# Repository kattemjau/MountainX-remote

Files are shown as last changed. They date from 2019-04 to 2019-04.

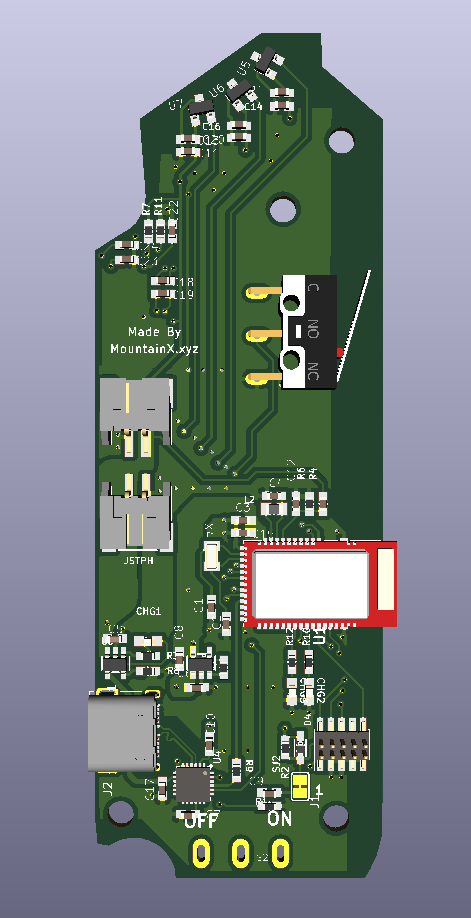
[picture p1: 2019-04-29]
Images/Front.PNG

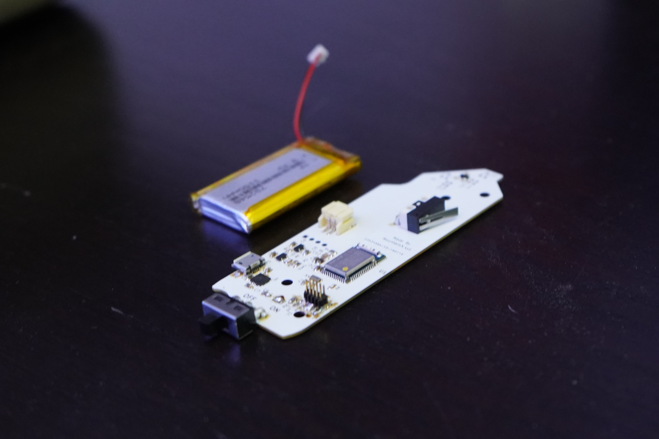
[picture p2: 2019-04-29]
Images/DSC02161.JPG

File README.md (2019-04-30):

# MountainX-remote
PCB of remote, designed in Kicad
Inspired by Adafruit, and SolidGeek

https://learn.adafruit.com/bluefruit-nrf52-feather-learning-guide?view=all#downloads

https://www.electric-skateboard.builders/t/simple-3d-printed-nrf-remote-arduino-controlled/28543

V3 is not yet tested

Arduino compadible CODE can be found here:
https://github.com/Heplaphon/MountainX-Remote

Follow setupguide from Adafruit: https://learn.adafruit.com/bluefruit-nrf52-feather-learning-guide?view=all#arduino-bsp-setup

V2 up and working with Arduino IDE, can be programmed over USB, JTAG and OTA (bluetooth)

3D model of PCB can be found here:
https://github.com/kattemjau/MountainX-remote/tree/master/3D%20model

3D model of remote can be found here:
https://github.com/kattemjau/MountainX-remote/tree/master/3D%20model/V2

Images can be found here:
https://github.com/kattemjau/MountainX-remote/tree/master/Images

Features:

3 Hall sensors for more accurate readings, 
Nordic NRF52 Bluetooth 5, Arm Cotex m4,
Oled screen with telematry from Vesc: Speed, distance, battery voltage, error codes e.t.c, 
Remote battery reading, 
1A Fast charger, 
Long battery life, 
Dual battery to prevent battery disconnect due to shaking, 
Spring loaded knob and trigger, 
Deadmans switch, 
Opensource reprogrammable firmware with arduino IDE, 
Connects with up to 20 clients, long range and high bandwidth,

Changes:

3D model now available, 
Integrated OLED screen, 
Correct angles on Hall sensors, 
Extra battery plug, 
More leds, 
More decoupling caps, 
Better layout, 
Changes to footprints, 
NOW USB C, 

Note:
Jtag programming header is mirrored, just flip the cable to get it to work. "Jtag is not needed"
https://shop-us.segger.com/J_Link_EDU_mini_p/8.08.91.htm

Footprint for Raytac NRF52832 not correct, and SS12D11 (SWITCH) is missing

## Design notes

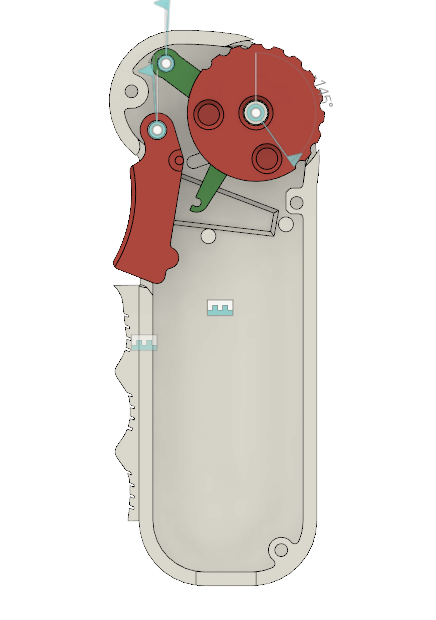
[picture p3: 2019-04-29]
Images/Mechanics.PNG

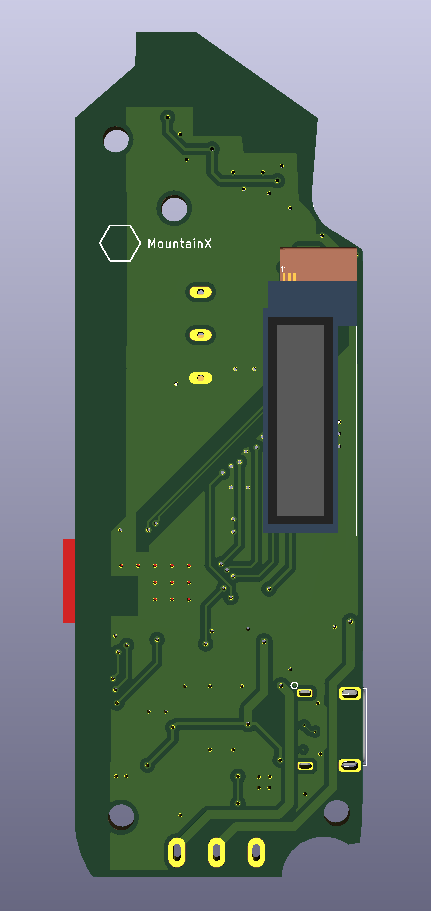
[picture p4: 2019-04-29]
Images/Back.PNG

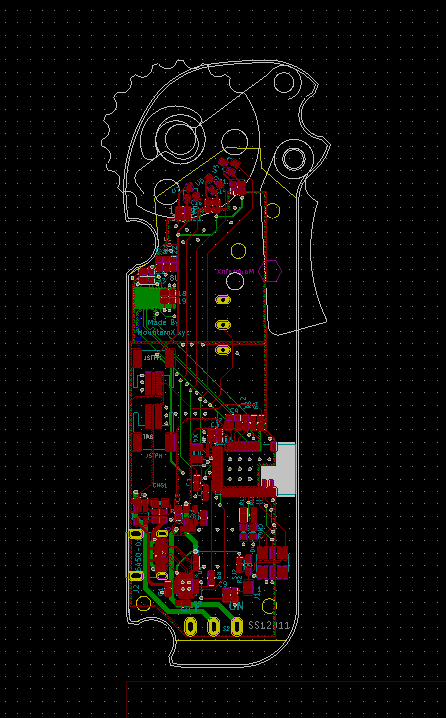
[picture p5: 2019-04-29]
Images/BRD.PNG

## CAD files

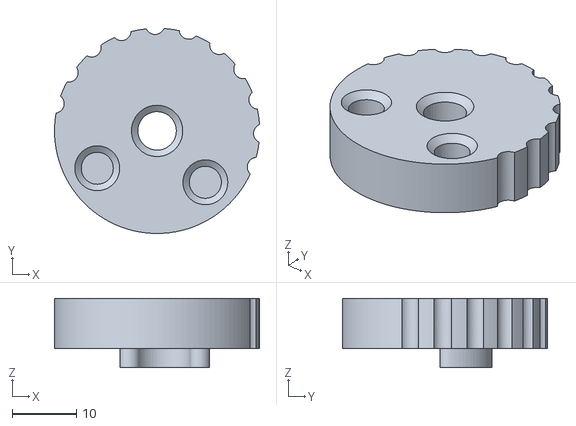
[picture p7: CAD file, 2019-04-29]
3D model/V2/wheel.stl
32.0 x 32.0 x 10.8

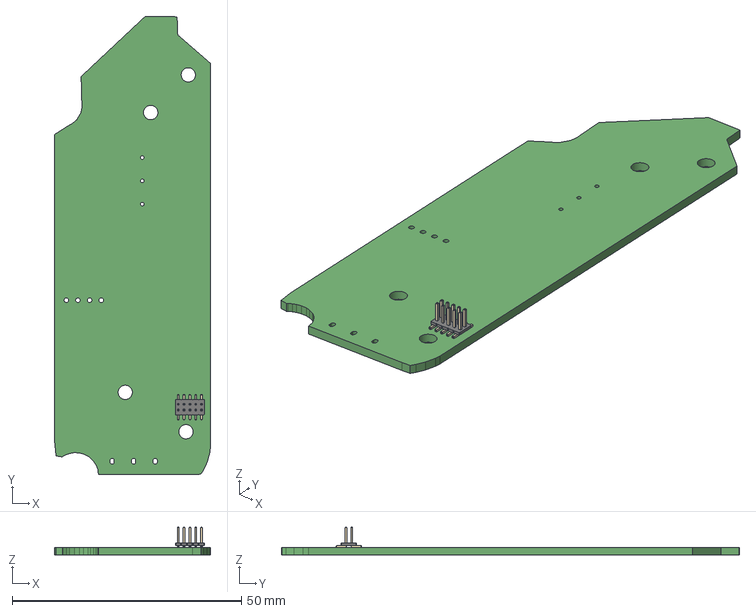
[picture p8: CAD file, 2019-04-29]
eBoard_remote_control.step
34.0 x 99.9 x 6.05 mm

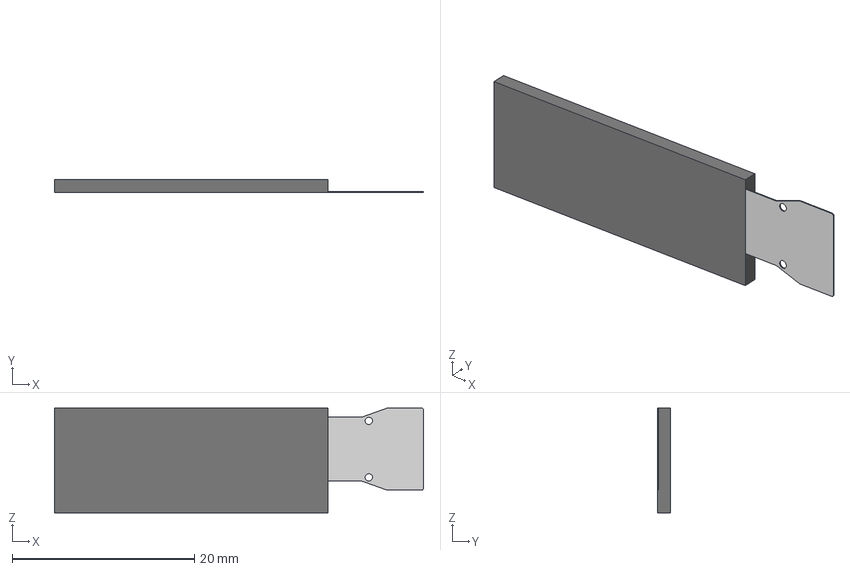
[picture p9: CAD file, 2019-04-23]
KiCad-SSD1306_OLED-0.91-128x32-master/KiCad-SSD1306_OLED-0.91-128x32-master/SSD1306_OLED-0.91-128x32.step
40.5 x 1.45 x 11.5 mm

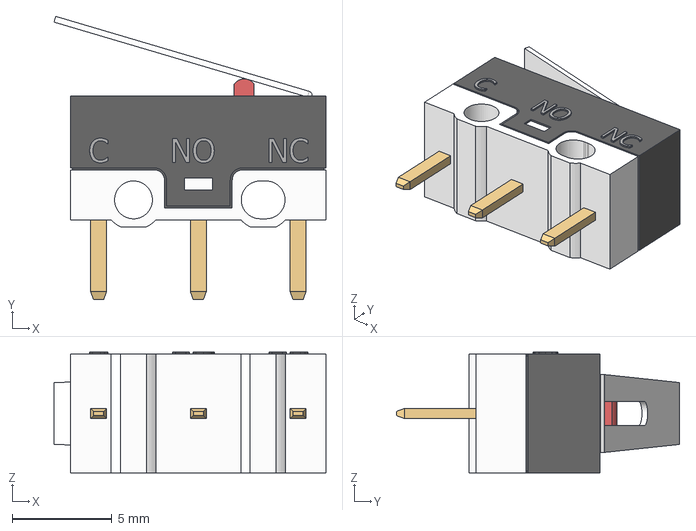
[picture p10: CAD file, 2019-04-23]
KiCad-SSD1306_OLED-0.91-128x32-master/SIngle part PCB micro switch.stp
13.6 x 14.2 x 6.05 mm

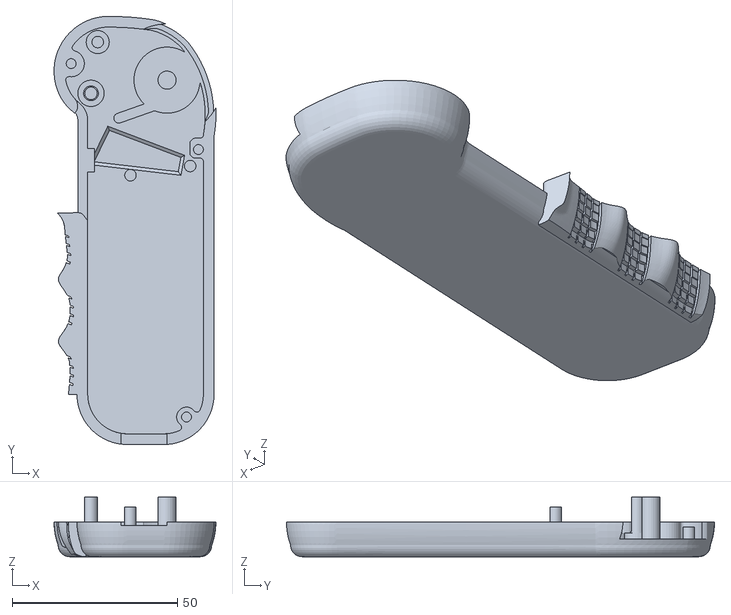
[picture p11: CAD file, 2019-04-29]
3D model/V2/Back.stl
49.0 x 129.5 x 18.0

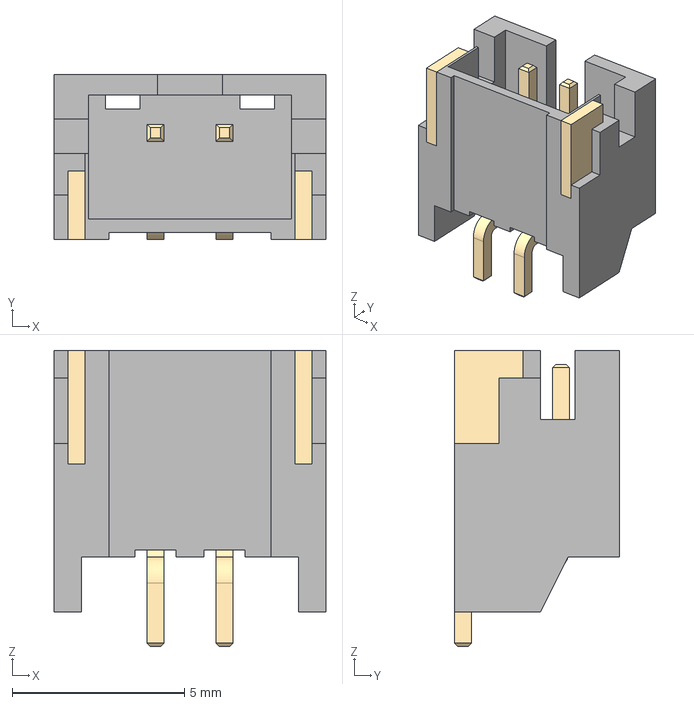
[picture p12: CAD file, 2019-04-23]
KiCad-SSD1306_OLED-0.91-128x32-master/S2B-PH-SM4-TB.step
7.90 x 4.80 x 8.60 mm

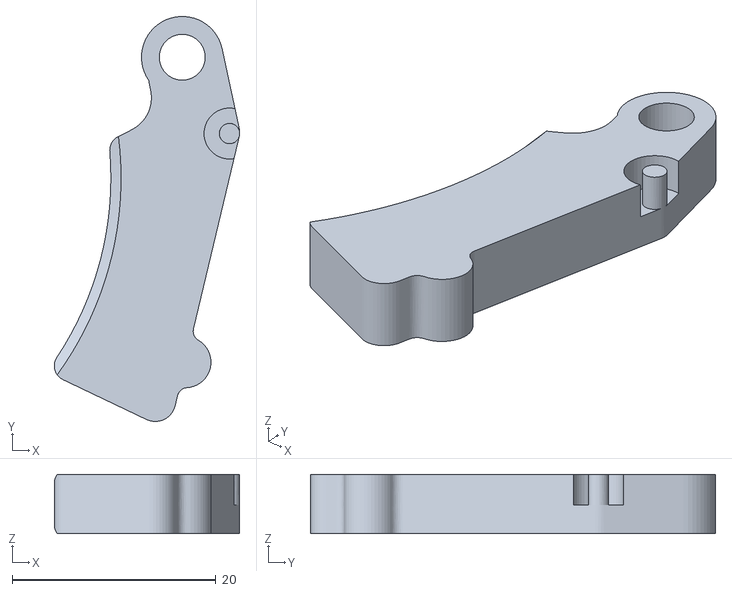
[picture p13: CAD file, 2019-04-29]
3D model/V2/Trigger.stl
18.2 x 39.7 x 5.80

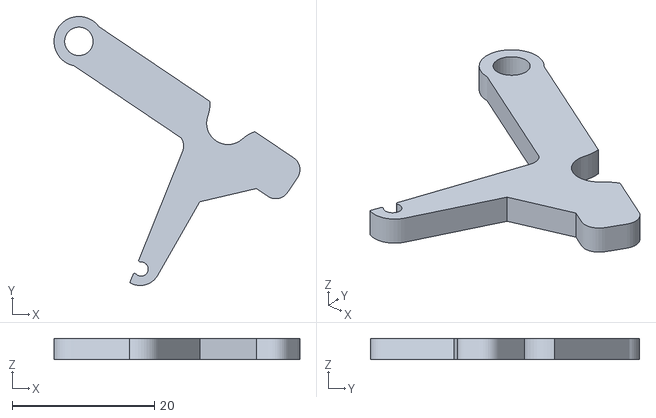
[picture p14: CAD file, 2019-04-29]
3D model/V2/Lever.stl
34.6 x 37.8 x 3.00

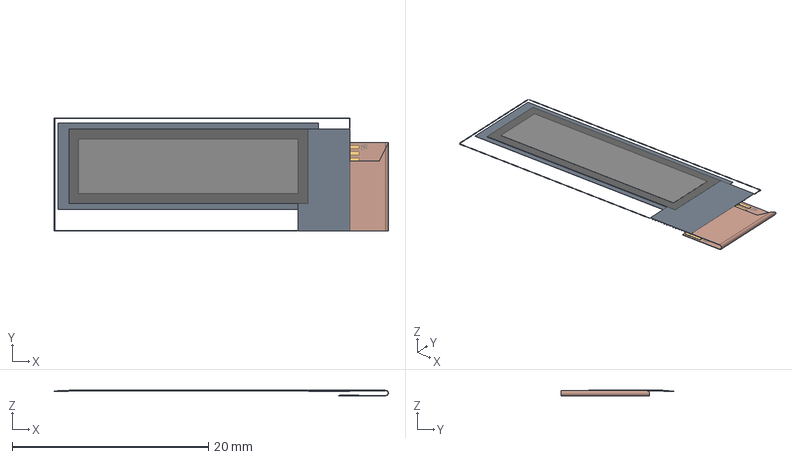
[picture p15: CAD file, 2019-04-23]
KiCad-SSD1306_OLED-0.91-128x32-master/0.91in OLED - Folded Flush - Without Glass.stp
34.1 x 11.5 x 0.621 mm

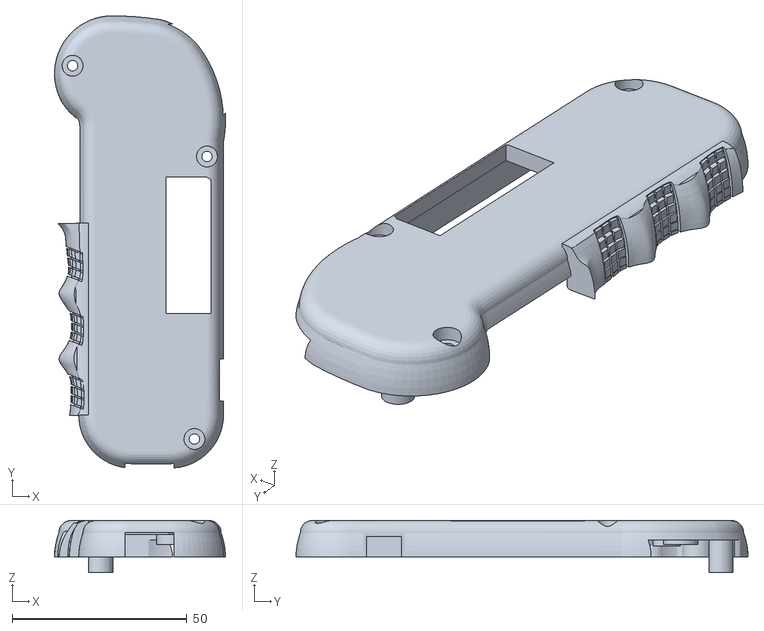
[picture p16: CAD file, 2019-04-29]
3D model/V2/Front.stl
49.0 x 129.5 x 14.9

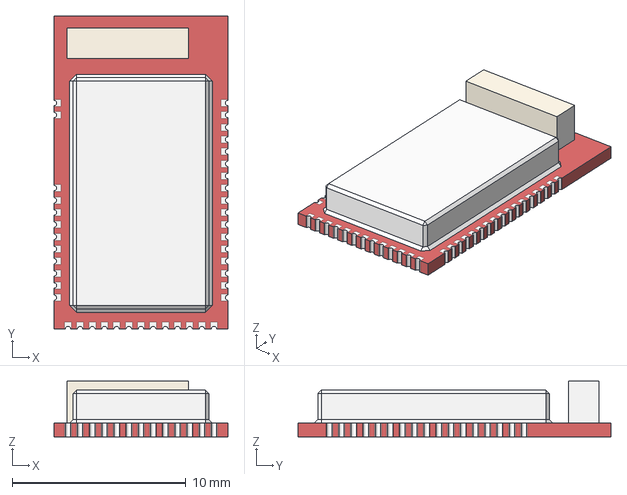
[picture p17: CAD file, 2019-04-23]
KiCad-SSD1306_OLED-0.91-128x32-master/Raytac-MDBT40.step
10.0 x 18.0 x 3.20 mm

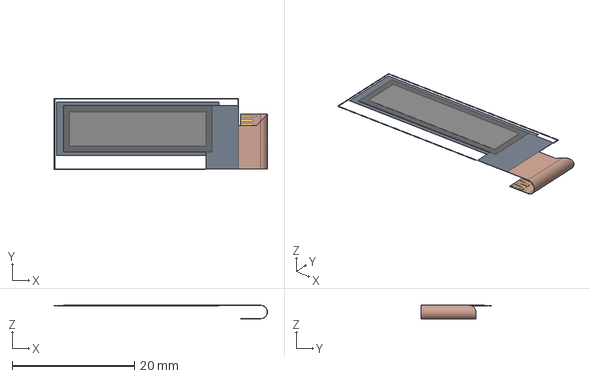
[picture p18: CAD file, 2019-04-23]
KiCad-SSD1306_OLED-0.91-128x32-master/0.91in OLED - Folded - Without Glass.stp
34.9 x 11.5 x 2.29 mm

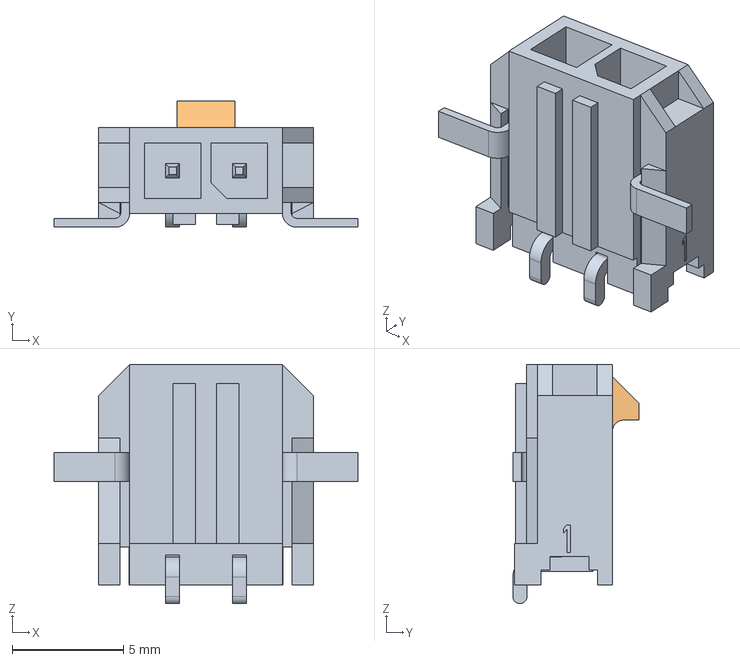
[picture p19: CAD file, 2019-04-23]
KiCad-SSD1306_OLED-0.91-128x32-master/43650-0212_stp/436500212.stp
13.7 x 5.67 x 10.7 mm

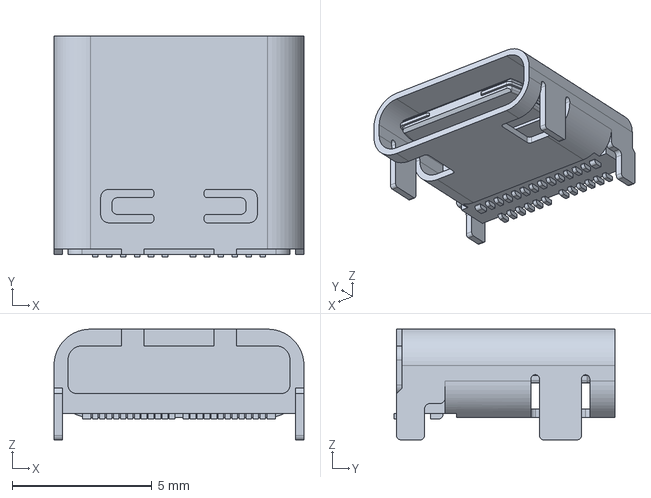
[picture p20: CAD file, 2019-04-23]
KiCad-SSD1306_OLED-0.91-128x32-master/1054500101.stp
8.94 x 7.90 x 3.96 mm

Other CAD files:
KiCad-SSD1306_OLED-0.91-128x32-master/S2B-PH-SM4-TB.SLDPRT

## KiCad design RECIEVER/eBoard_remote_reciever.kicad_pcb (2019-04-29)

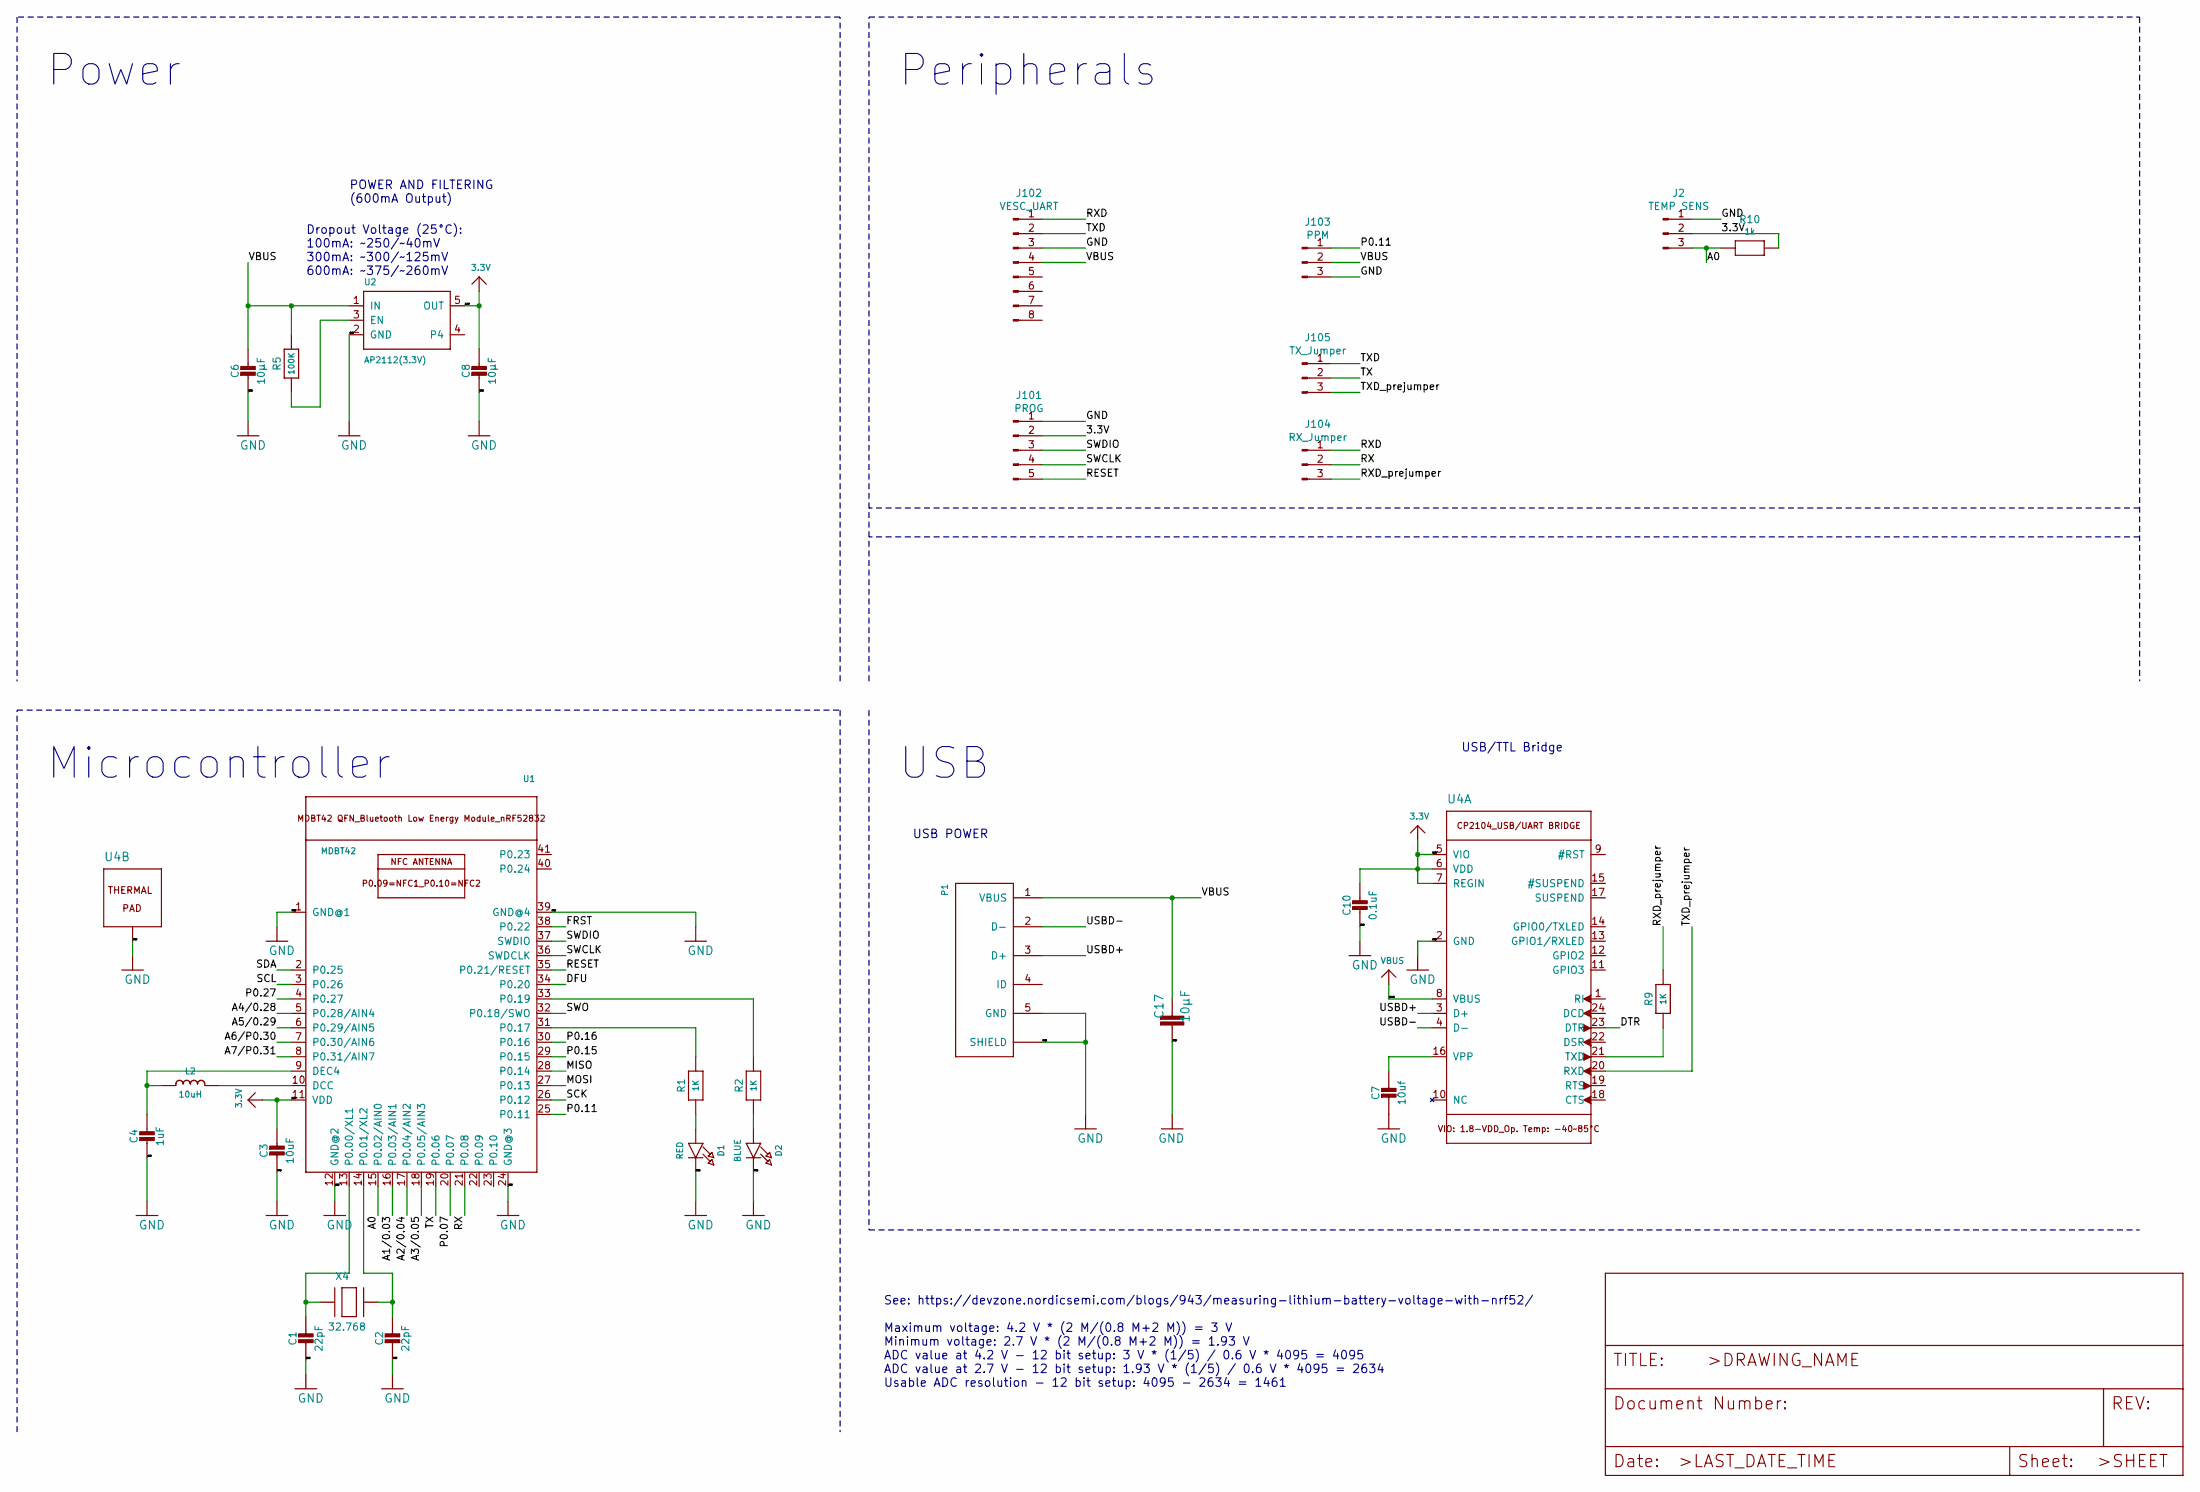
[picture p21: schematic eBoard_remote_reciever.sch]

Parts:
C1, C2: 22pF; 0603-NO
C3: 10uF; 0805-NO
C4: 1uF; 0603-NO
C6, C8: 10µF; 0805-NO
C7: 10uf; 0805-NO
C10: 0.1uF; 0603-NO
C17: 10µF; C0603
D1: RED; D_0805_2012Metric
D2: BLUE; D_0805_2012Metric
J2: TEMP SENS; PinHeader_1x03_P2.54mm_Vertical
J101: PROG; PinHeader_1x05_P2.54mm_Vertical
J102: VESC_UART; PinHeader_1x09_P2.54mm_Vertical
J103: PPM; PinHeader_1x03_P2.54mm_Vertical
J104: RX_Jumper; PinHeader_1x03_P2.54mm_Vertical
J105: TX_Jumper; PinHeader_1x03_P2.54mm_Vertical
L2: 10uH; 0805-NO
P1: USB; USB-MICRO-B
R1, R2, R9: 1K; 0603-NO
R5: 100K; 0603-NO
R10: 1k; R_0603_1608Metric
U1: MDBT42; BLE_MODULE_RAYTAC_MDBT42
U2: AP2112(3.3V); SOT23-5
U4: CP2104; QFN24_4MM_SMSC
X4: 32.768; XTAL3215

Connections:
3.3V: C3.1, C8.1, C10.1, J2.2, J101.2, R10.1, U1.11 (VDD), U2.5 (OUT), U4.5 (VIO), U4.6 (VDD), U4.7 (REGIN)
/A0: J2.3, R10.2, U1.15 (P0.02/AIN0)
/A1/0.03: U1.16 (P0.03/AIN1)
/A2/0.04: U1.17 (P0.04/AIN2)
/A3/0.05: U1.18 (P0.05/AIN3)
/A4/0.28: U1.5 (P0.28/AIN4)
/A5/0.29: U1.6 (P0.29/AIN5)
/A6/P0.30: U1.7 (P0.30/AIN6)
/A7/P0.31: U1.8 (P0.31/AIN7)
/DFU: U1.34 (P0.20)
/DTR: U4.23 (DTR)
/FRST: U1.38 (P0.22)
/MISO: U1.28 (P0.14)
/MOSI: U1.27 (P0.13)
/P0.07: U1.20 (P0.07)
/P0.11: J103.1, U1.25 (P0.11)
/P0.15: U1.29 (P0.15)
/P0.16: U1.30 (P0.16)
/P0.27: U1.4 (P0.27)
/RESET: J101.5, U1.35 (P0.21/RESET)
/RX: J104.2, U1.21 (P0.08)
/RXD: J102.1, J104.1
/RXD_prejumper: J104.3, R9.2
/SCK: U1.26 (P0.12)
/SCL: U1.3 (P0.26)
/SDA: U1.2 (P0.25)
/SWCLK: J101.4, U1.36 (SWDCLK)
/SWDIO: J101.3, U1.37 (SWDIO)
/SWO: U1.32 (P0.18/SWO)
/TX: J105.2, U1.19 (P0.06)
/TXD: J102.2, J105.1
/TXD_prejumper: J105.3, U4.20 (RXD)
/USBD+: P1.3 (D+), U4.3 (D+)
/USBD-: P1.2 (D-), U4.4 (D-)
GND: C1.2, C2.2, C3.2, C4.2, C6.2, C7.2, C8.2, C10.2, C17.2, D1.C, D2.C, J2.1, J101.1, J102.3, J103.3, P1.5 (GND), P1.G1 (SHIELD), P1.G2 (SHIELD), P1.G3 (SHIELD), P1.G4 (SHIELD), U1.1 (GND@1), U1.12 (GND@2), U1.24 (GND@3), U1.39 (GND@4), U2.2 (GND), U4.2 (GND), U4.THERM (TP)
unnamed: C1.1, U1.13 (P0.00/XL1), X4.P$1
unnamed: C2.1, U1.14 (P0.01/XL2), X4.P$2
unnamed: C4.1, L2.1, U1.9 (DEC4)
unnamed: C7.1, U4.16 (VPP)
unnamed: D1.A, R1.1
unnamed: D2.A, R2.1
unnamed: L2.2, U1.10 (DCC)
unnamed: R1.2, U1.31 (P0.17)
unnamed: R2.2, U1.33 (P0.19)
unnamed: R5.1, U2.3 (EN)
unnamed: R9.1, U4.21 (TXD)
VBUS: C6.1, C17.1, J102.4, J103.2, P1.1 (VBUS), R5.2, U2.1 (IN), U4.8 (VBUS)

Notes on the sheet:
POWER AND FILTERING (600mA Output)
Dropout Voltage (25°C): 100mA: ~~250/~~40mV 300mA: ~~300/~~125mV 600mA: ~~375/~~260mV
USB POWER
USB/TTL Bridge
See: https://devzone.nordicsemi.com/blogs/943/measuring-lithium-battery-voltage-with-nrf52/ Maximum voltage: 4.2 V * (2 M/(0.8 M+2 M)) = 3 V Minimum voltage: 2.7 V * (2 M/(0.8 M+2 M)) = 1.93 V ADC value at 4.2 V - 12 bit setup: 3 V * (1/5) / 0.6 V * 4095 = 4095 ADC value at 2.7 V - 12 bit setup: 1.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
Power
Peripherals
Microcontroller
USB

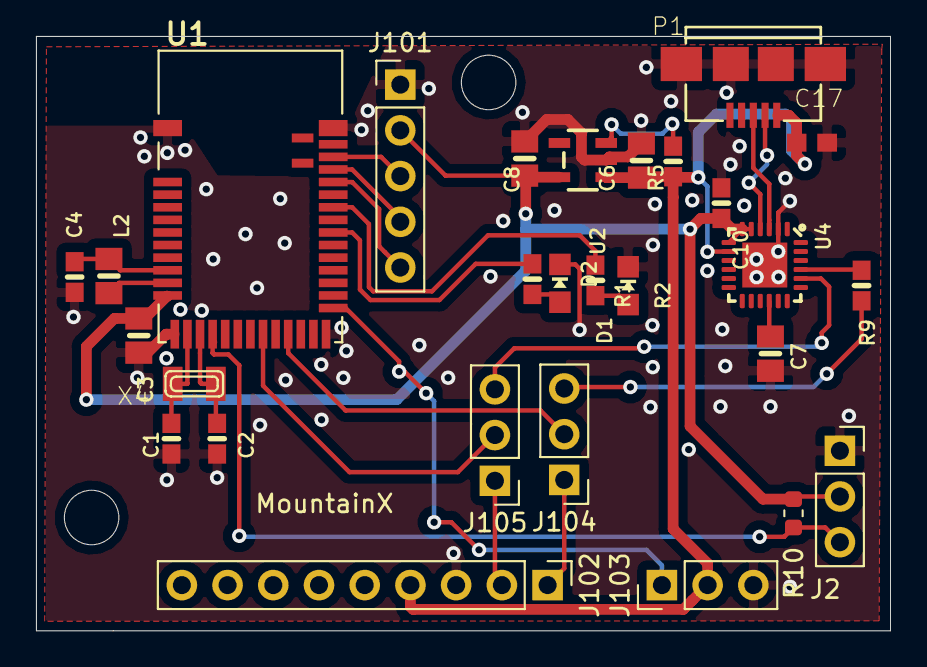
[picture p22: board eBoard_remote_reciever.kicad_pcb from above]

Board: 2 copper layers, 47.4 x 33.0 mm, 28 parts (0 on the bottom side), 27 nets.

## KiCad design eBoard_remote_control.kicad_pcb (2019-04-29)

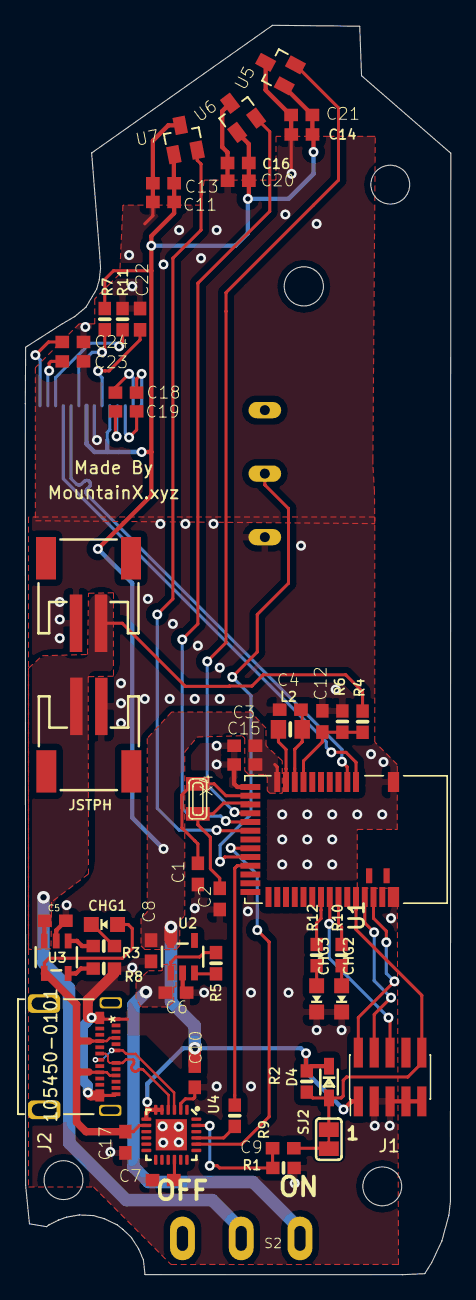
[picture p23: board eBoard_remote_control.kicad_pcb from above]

Board: 2 copper layers, 34.0 x 99.9 mm, 57 parts (0 on the bottom side), 45 nets.

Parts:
C1, C2: 22pF; C0603
C3, C23, C24: 10uF; C0603
C4, C18, C19, C22: 1uF; C0603
C5, C6, C8, C11, C14, C17, C20: 10µF; C0603
C7: 10uf; C0603
C9, C10: 0.1uF; C0603
C12: 1nF; C0603
C13, C15, C16, C21: 100nF; C0603
CHG1, CHG2, CHG3: BLUE; CHIPLED_0805_NOOUTLINE
D4: 1n4148; SOD-323
J1: SWDIO_conn; PinHeader_2x05_P1.27mm_Vertical_SMD
J2: 105450-0101
L2: 10uH; 0805-NO
R1, R3, R8, R9, R10, R12: 1K; 0603-NO
R2, R7: 10K; 0603-NO
R4: 806K; 0603-NO
R5: 100K; 0603-NO
R6: 2M; 0603-NO
R11: 390k; 0603-NO
S1: K9-1267B-L
S2: SS12D11
SJ2: BAT; SOLDERJUMPER_CLOSEDWIRE
U1: MDBT42; BLE_MODULE_RAYTAC_MDBT42
U2: AP2112(3.3V); SOT23-5
U3: MCP73831T-2ACI/OT; SOT23-5
U4: CP2104; QFN24_4MM_SMSC
U5, U6, U7: AH49ENTR-G1; SOT23
U8: SSD1306; SSD1306_OLED-0.91-128x32
X1, X2: JSTPH; JSTPH2
X4: 32.768; XTAL3215

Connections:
3.3V: C3.1, C8.1, C10.1, C11.1, C13.1, C14.1, C15.1, C16.1, C20.1, C21.1, D4.C, J1.1, R2.1, R7.2, U1.11, U2.5, U4.5, U4.6, U4.7, U5.1, U6.1, U7.1, U8.5, U8.8
/A0: U1.15, U5.2
/A1: U1.16, U6.2
/A2: U1.17, U7.2
/A7/P0.31: C12.1, R4.2, R6.1, U1.8
/DTR: C9.2, R1.2, U4.23
/P0.07: S1.P2, U1.20
/RESET: D4.A, J1.10, R2.2, SJ2.2, U1.35
/RXD: R9.2, U1.21
/SWCLK: J1.4, U1.36
/SWDIO: J1.2, U1.37
/SWO: J1.6, U1.32
/TXD: U1.19, U4.20
/VBB: C6.1, R5.2, S2.1, U2.1
GND: C1.2, C2.2, C3.2, C4.2, C5.2, C6.2, C7.2, C8.2, C10.2, C11.2, C12.2, C13.2, C14.2, C15.2, C16.2, C17.2, C20.2, C21.2, C22.1, C23.1, C24.1, CHG2.C, CHG3.C, J1.3, J1.5, J1.7, J1.9, J2.A1, J2.A12, J2.B1, J2.B12, R1.1, R6.2, R8.2, R11.2, S1.P1, U1.1, U1.12, U1.24, U1.39, U2.2, U3.2, U4.2, U4.THERM, U5.3, U6.3, U7.3, U8.7, X1.1, X2.1
unnamed: C1.1, U1.13, X4.P$1
unnamed: C2.1, U1.14, X4.P$2
unnamed: C4.1, L2.1, U1.9
unnamed: C7.1, U4.16
unnamed: C9.1, SJ2.1
unnamed: C18.1, U8.1
unnamed: C18.2, U8.2
unnamed: C19.1, U8.3
unnamed: C19.2, U8.4
unnamed: C22.2, U8.6
unnamed: C23.2, U8.13
unnamed: C24.2, U8.14
unnamed: CHG1.C, R3.1
unnamed: CHG2.A, R10.1
unnamed: CHG3.A, R12.1
unnamed: L2.2, U1.10
unnamed: R3.2, U3.1
unnamed: R5.1, U2.3
unnamed: R7.1, U8.9
unnamed: R8.1, U3.5
unnamed: R9.1, U4.21
unnamed: R10.2, U1.33
unnamed: R11.1, U8.12
unnamed: R12.2, U1.31
SCL: U1.3, U8.10
SDA: U1.2, U8.11
USBD+: J2.A6, J2.B6, U4.3
USBD-: J2.A7, J2.B7, U4.4
VBAT: C5.1, R4.1, S2.2, U3.3, X1.2, X2.2
VBUS: C17.1, CHG1.A, J2.A4, J2.A9, J2.B4, J2.B9, U3.4, U4.8

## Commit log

2019-01-08 V2 update
    [eBoard_remote_control.kicad_pcb, eBoard_remote_control.sch]
2019-04-23 added dual jst and 3d models
    [eBoard_remote_control.kicad_pcb]
2019-04-23 oled schem
    [_saved_eBoard_remote_control.sch, eBoard_remote_control.kicad_pcb, eBoard_remote_control.sch]
2019-04-24 started Layout V3
    [eBoard_remote_control.kicad_pcb, eBoard_remote_control.sch]
2019-04-24 added rgb led V3
    [eBoard_remote_control.kicad_pcb, eBoard_remote_control.sch]
2019-04-27 updated 3d modelis
    [eBoard_remote_control.kicad_pcb]
2019-04-29 Added 3D models
    [Back.stl, Front.stl, Lever.stl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]

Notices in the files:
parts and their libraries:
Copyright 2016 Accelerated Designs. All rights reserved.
